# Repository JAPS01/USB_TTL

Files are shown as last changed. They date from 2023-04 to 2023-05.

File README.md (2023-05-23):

## USB to TTL converter 

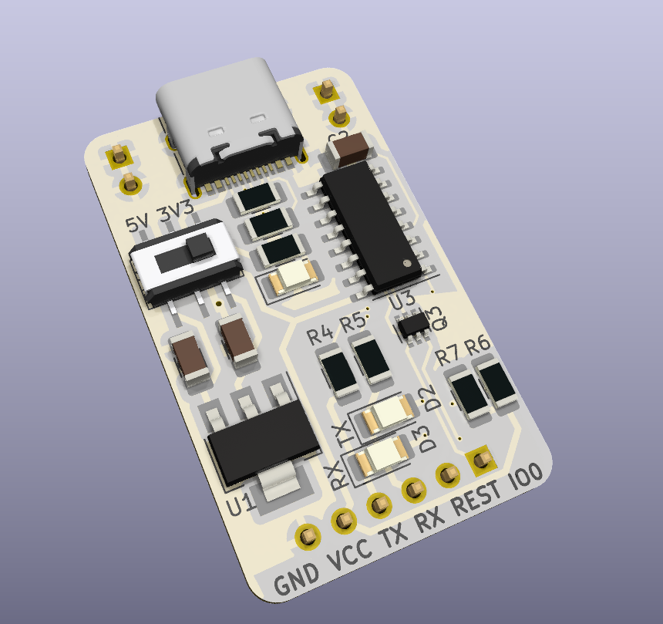
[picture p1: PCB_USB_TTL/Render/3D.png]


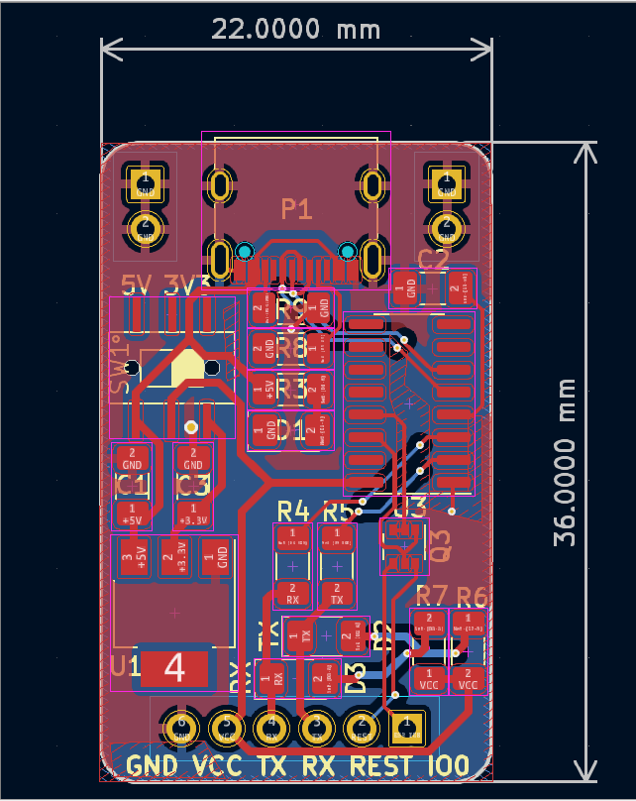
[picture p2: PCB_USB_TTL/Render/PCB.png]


USB to TTL converter using ch340c, with a small size and compatible with 5V and 3.3V voltages.

It already has pins for micro reset without having to press the reset button.

## Installation

Install Drivers

You can use sparkfun installation guide for drivers: 
https://learn.sparkfun.com/tutorials/how-to-install-ch340-drivers/all#mac-osx

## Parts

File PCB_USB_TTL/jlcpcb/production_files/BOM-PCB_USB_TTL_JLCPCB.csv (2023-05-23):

Comment | Designator | Footprint | LCSC
1K | R3,R4,R5,R6,R7 | R_1206_3216Metric_Pad1.30x1.75mm_HandSolder | C112223
UMH3N | Q3 | SOT-363_SC-70-6 | C123008
5K | R8,R9 | R_1206_3216Metric_Pad1.30x1.75mm_HandSolder | C136458
USB_C_Plug | P1 | USB_C_Receptacle_XKB_U262-16XN-4BVC11 | C319148
1uF | C1,C3 | C_1206_3216Metric_Pad1.33x1.80mm_HandSolder | C326607
100nF | C2 | C_1206_3216Metric_Pad1.33x1.80mm_HandSolder | C82601
CH340C | U3 | SOIC-16_3.9x9.9mm_P1.27mm | C84681
AZ1117H-3.3TRE1 | U1 | SOT-223 | C92517
~ | SW1 | MS-22D28-G020 | C963205
LED_RED | D1 | LED_1206_3216Metric_Pad1.42x1.75mm_HandSolder | C965822
TX | D2,D3 | LED_1206_3216Metric_Pad1.42x1.75mm_HandSolder | C965826

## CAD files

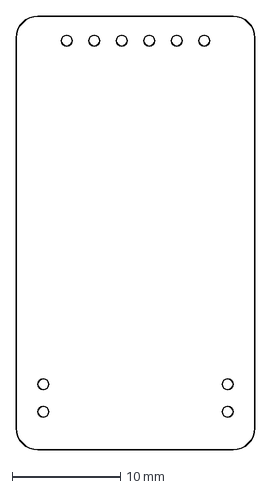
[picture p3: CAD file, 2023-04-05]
PCB_USB_TTL/DXF/USB board with holoe.dxf
22.0 x 40.0 mm

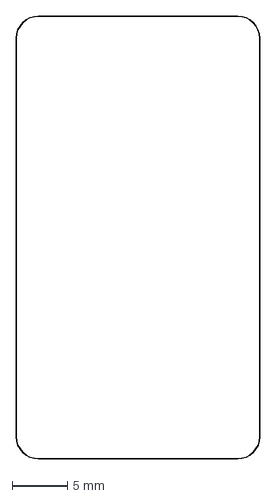
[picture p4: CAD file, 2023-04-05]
PCB_USB_TTL/DXF/Board.dxf
22.0 x 40.0 mm

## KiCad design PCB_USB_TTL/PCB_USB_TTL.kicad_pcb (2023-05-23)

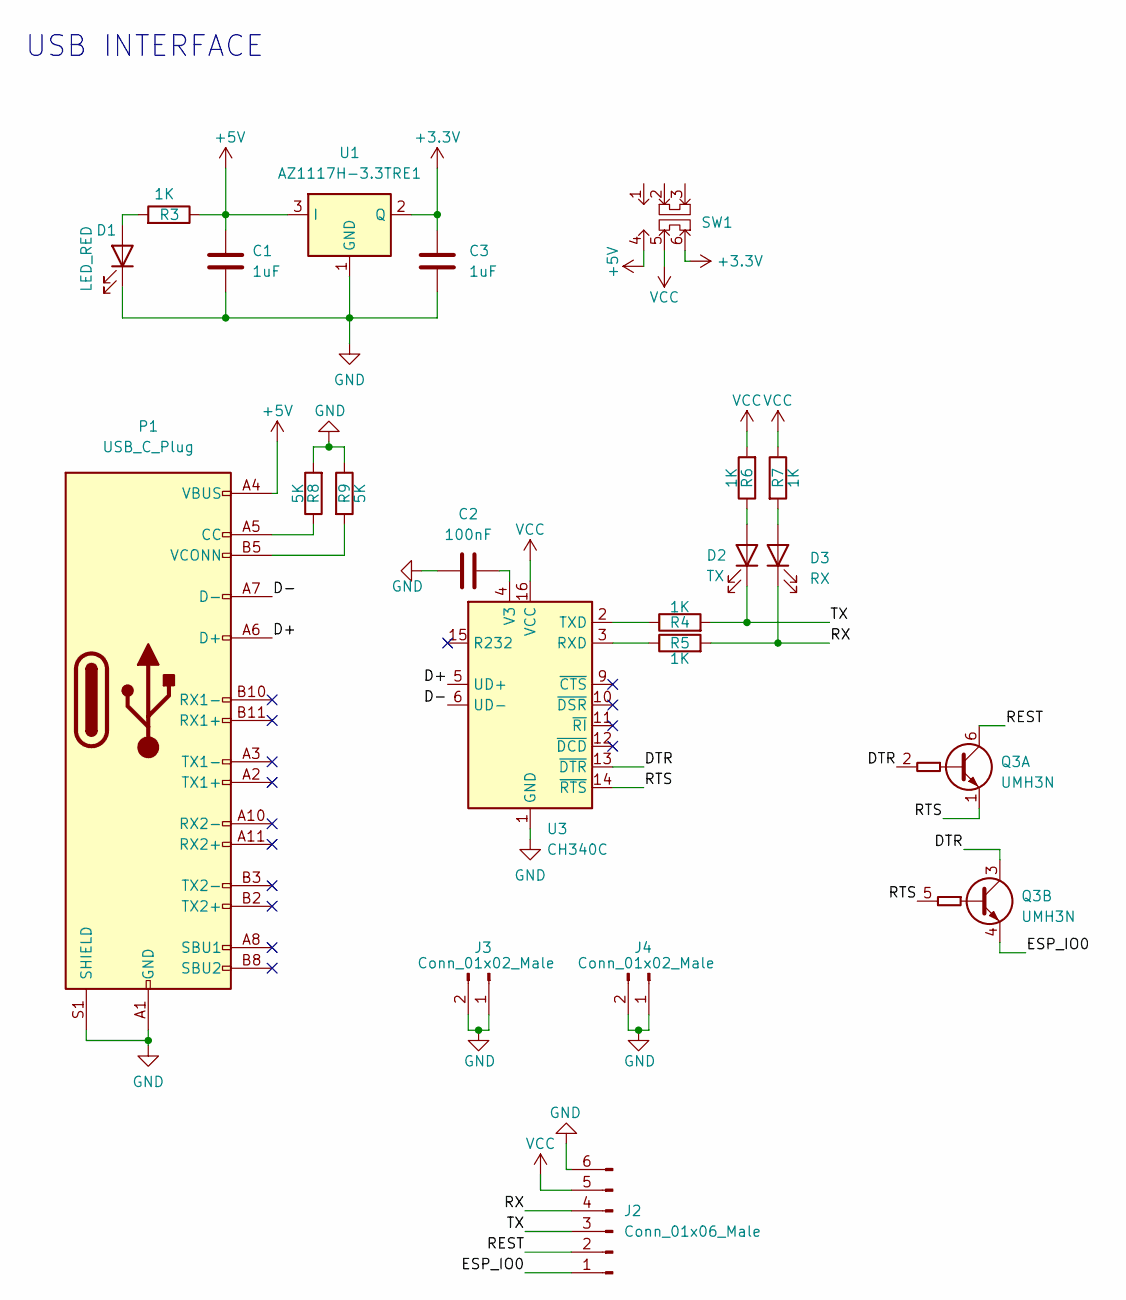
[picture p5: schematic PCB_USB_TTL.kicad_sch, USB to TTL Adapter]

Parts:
C1, C3: 1uF; C_1206_3216Metric_Pad1.33x1.80mm_HandSolder
C2: 100nF; C_1206_3216Metric_Pad1.33x1.80mm_HandSolder
D1: LED_RED; LED_1206_3216Metric_Pad1.42x1.75mm_HandSolder
D2: TX; LED_1206_3216Metric_Pad1.42x1.75mm_HandSolder
D3: RX; LED_1206_3216Metric_Pad1.42x1.75mm_HandSolder
J2: Conn_01x06_Male; PinHeader_1x06_P2.54mm_Vertical
J3, J4: Conn_01x02_Male; PinHeader_1x02_P2.54mm_Vertical
P1: USB_C_Plug; USB_C_Receptacle_XKB_U262-16XN-4BVC11
Q3: UMH3N; SOT-363_SC-70-6
R3, R4, R5, R6, R7: 1K; R_1206_3216Metric_Pad1.30x1.75mm_HandSolder
R8, R9: 5K; R_1206_3216Metric_Pad1.30x1.75mm_HandSolder
SW1: MS-22D28-G020
U1: AZ1117H-3.3TRE1; SOT-223
U3: CH340C; SOIC-16_3.9x9.9mm_P1.27mm

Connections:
+3.3V: C3.1, SW1.6, U1.2 (Q)
+5V: C1.1, P1.A4 (VBUS), P1.A9 (VBUS), P1.B4 (VBUS), P1.B9 (VBUS), R3.1, SW1.4, U1.3 (I)
/D+: P1.A6 (D+), U3.5 (UD+)
/D-: P1.A7 (D-), U3.6 (UD-)
/DTR: Q3.2 (B1), Q3.3 (C2), U3.13 (~DTR)
/ESP_IO0: J2.1, Q3.4 (E2)
/REST: J2.2, Q3.6 (C1)
/RTS: Q3.1 (E1), Q3.5 (B2), U3.14 (~RTS)
/RX: D3.1 (K), J2.4, R5.2
/TX: D2.1 (K), J2.3, R4.2
GND: C1.2, C2.1, C3.2, D1.1 (K), J2.6, J3.1, J3.2, J4.1, J4.2, P1.A1 (GND), P1.A12 (GND), P1.B1 (GND), P1.B12 (GND), P1.S1 (SHIELD), R8.2, R9.1, U1.1 (GND), U3.1 (GND)
unnamed: D1.2 (A), R3.2
unnamed: D2.2 (A), R6.1
unnamed: D3.2 (A), R7.2
unnamed: P1.A5 (CC), R8.1
unnamed: P1.B5 (VCONN), R9.2
unnamed: R5.1, U3.3 (RXD)
unnamed: R4.1, U3.2 (TXD)
unnamed: C2.2, U3.4 (V3)
VCC: J2.5, R6.2, R7.1, SW1.5, U3.16 (VCC)

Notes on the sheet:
USB INTERFACE

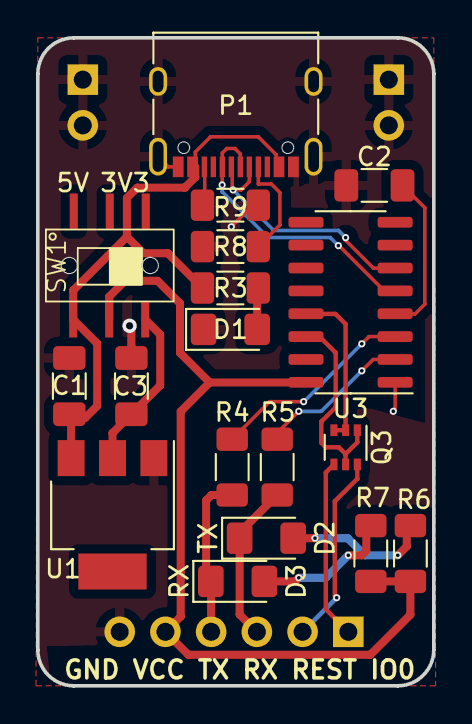
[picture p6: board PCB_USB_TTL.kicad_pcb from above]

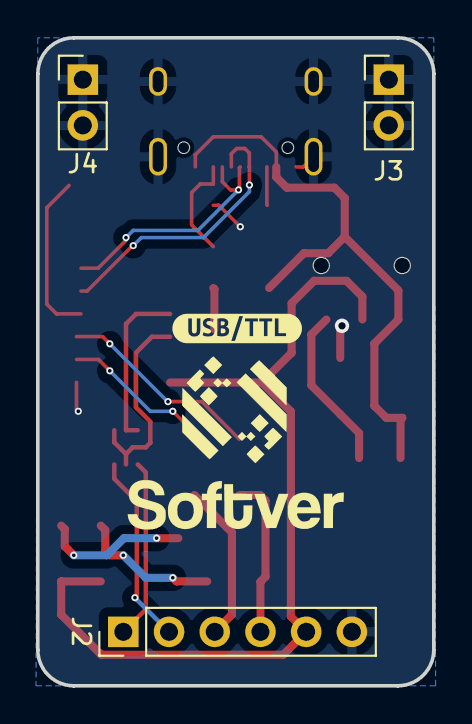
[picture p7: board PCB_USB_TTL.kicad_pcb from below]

Board: 2 copper layers, 22.0 x 36.0 mm, 22 parts (4 on the bottom side), 20 nets.

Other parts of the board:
kibuzzard-638F54F7: G***; kibuzzard-638F54F7

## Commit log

2023-04-05 PCB using CH340C
    [BOM-PCB_USB_TTL.csv, BOM-USB to TTL.csv, Board.dxf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]
2023-05-23 Rev 2
    Switch is added to change from 3.3v to 5v.
    UMH3N is used to save space and cost.
    [BOM-PCB_USB_TTL.csv, BOM-PCB_USB_TTL_JLCPCB.csv, BOM-USB to TTL.csv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]
